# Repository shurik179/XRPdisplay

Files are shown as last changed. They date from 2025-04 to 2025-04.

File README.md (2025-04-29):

# XRP display
This project describes a small TFT display designed for use  with [XRP robot](https://experientialrobotics.org/)

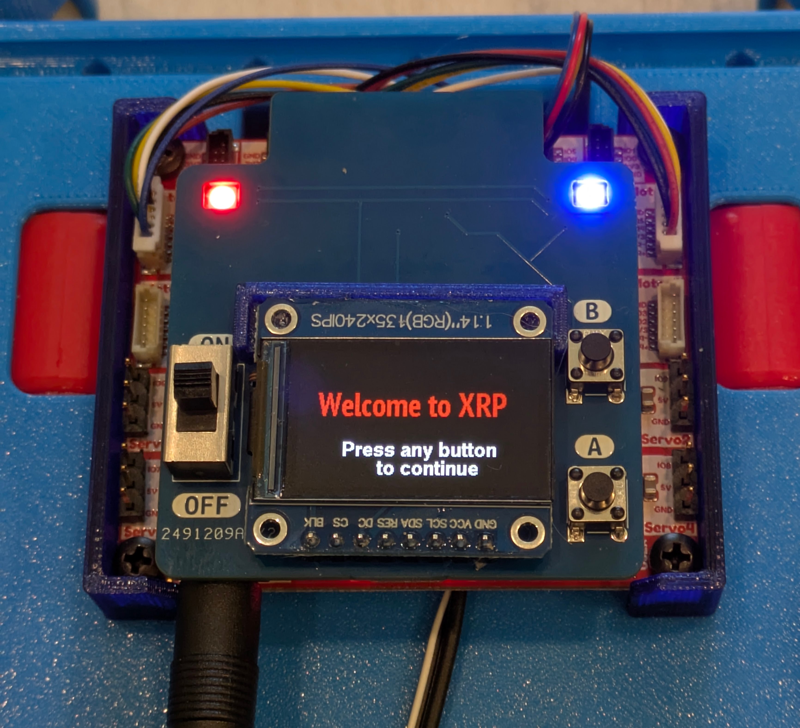
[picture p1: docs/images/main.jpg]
Main view


## Features

* 135x240 TFT SPI display
* two user buttons
* two addressable RGB LEDs (Neopixels)
* Power switch

## Documentation 
Detailed documentation is available at https://xrpdisplay.readthedocs.io/

## License
Everything in this repository is available under MIT license, except for the fonts in software/lib. See README file in that folder for license information.

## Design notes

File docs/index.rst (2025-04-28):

####################################
XRP display
####################################

Main view

This document describes the XRP display, an add-on board for `XRP robot <https://experientialrobotics.org/>`__

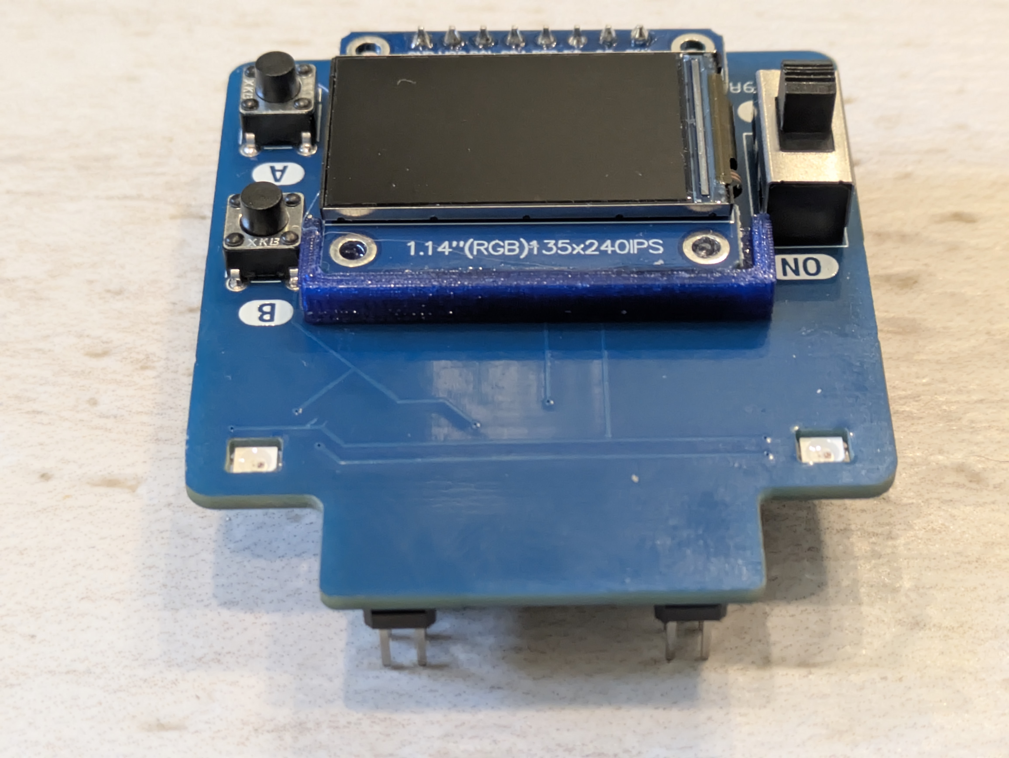
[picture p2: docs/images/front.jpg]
Front view


Below are the key features of this board.

* Plugs into the headers on XRP controller (warning: this doesn't work with Beta version!)
* provides a 135x240 color TFT display, using SPI bus of the XRP controller
* provides two addressable RGB LEDs (Neopixels)
* two user buttons 
* a power switch
* comes with an easy to use micropython library

All board design files and software are available from |github| under an open source license. 

.. toctree::
    :caption: Table of Contents
    :maxdepth: 1

    assembly
    usage

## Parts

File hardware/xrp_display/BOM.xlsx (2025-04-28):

Designator | Side | Description | Quantity | Link
D1, D2 | bottom | SK6812-MINI-E, reverse mount | 2 | C5149201 (https://www.lcsc.com/product-detail/RGB-LEDs-Built-in-IC_OPSCO-Optoelectronics-SK6812MINI-E_C5149201.html)
J1, J2 | bottom | PinHeader 2x20, SMD | 2 | C6332245 (https://www.lcsc.com/product-detail/Pin-Headers_Hanbo-Electronic-HB-PH9-254220PB2GOP_C6332245.html)
R1 | bottom | Resistor 0603, 33k | 1 | generic
SW1, SW2 | top | Tactile switch, 6x6mm | 2 | C381011 (https://www.lcsc.com/product-detail/Tactile-Switches_XKB-Connection-TC-1102-C-E-B_C381011.html)
SW3 | top | SPDT switch, SS12D | 1 | C319013 (https://www.lcsc.com/product-detail/Toggle-Switches_XKB-Connectivity-SS-12D10L3_C319013.html)
U1 | top | TFT_135x240_1_14in | 1 | AliExpress (https://www.aliexpress.us/item/3256801198423367.html)

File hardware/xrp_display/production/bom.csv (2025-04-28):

Designator | Footprint | Quantity | Value | LCSC Part #
D1, D2 | SK6812-MINI-E | 2 | SK6812MINI-E
J1, J2 | PinHeader_2x20_P2.54mm_Vertical_SMD | 2 | Conn_02x20_Odd_Even | C6332245
R1 | 0603 | 1 | 33k
SW1, SW2 | SW_TH_Tactile_Omron_B3F-10xx | 2 | SW_SPST
SW3 | SW_XKB_SS12D10L3 | 1 | SW_SPDT
U1 | TFT_135x240_1_14in | 1 | ST7789-TFT

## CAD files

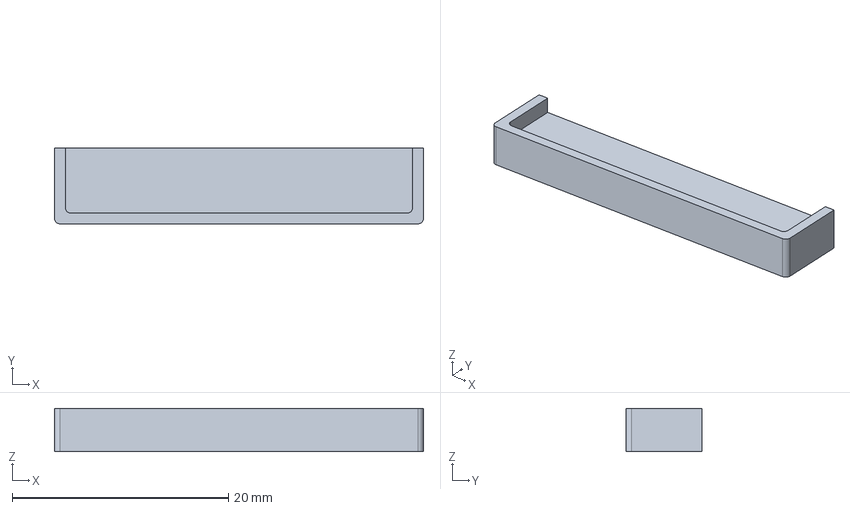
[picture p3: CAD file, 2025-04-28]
hardware/3dprinted/SPI display support v3.step
34.1 x 7.00 x 4.00 mm

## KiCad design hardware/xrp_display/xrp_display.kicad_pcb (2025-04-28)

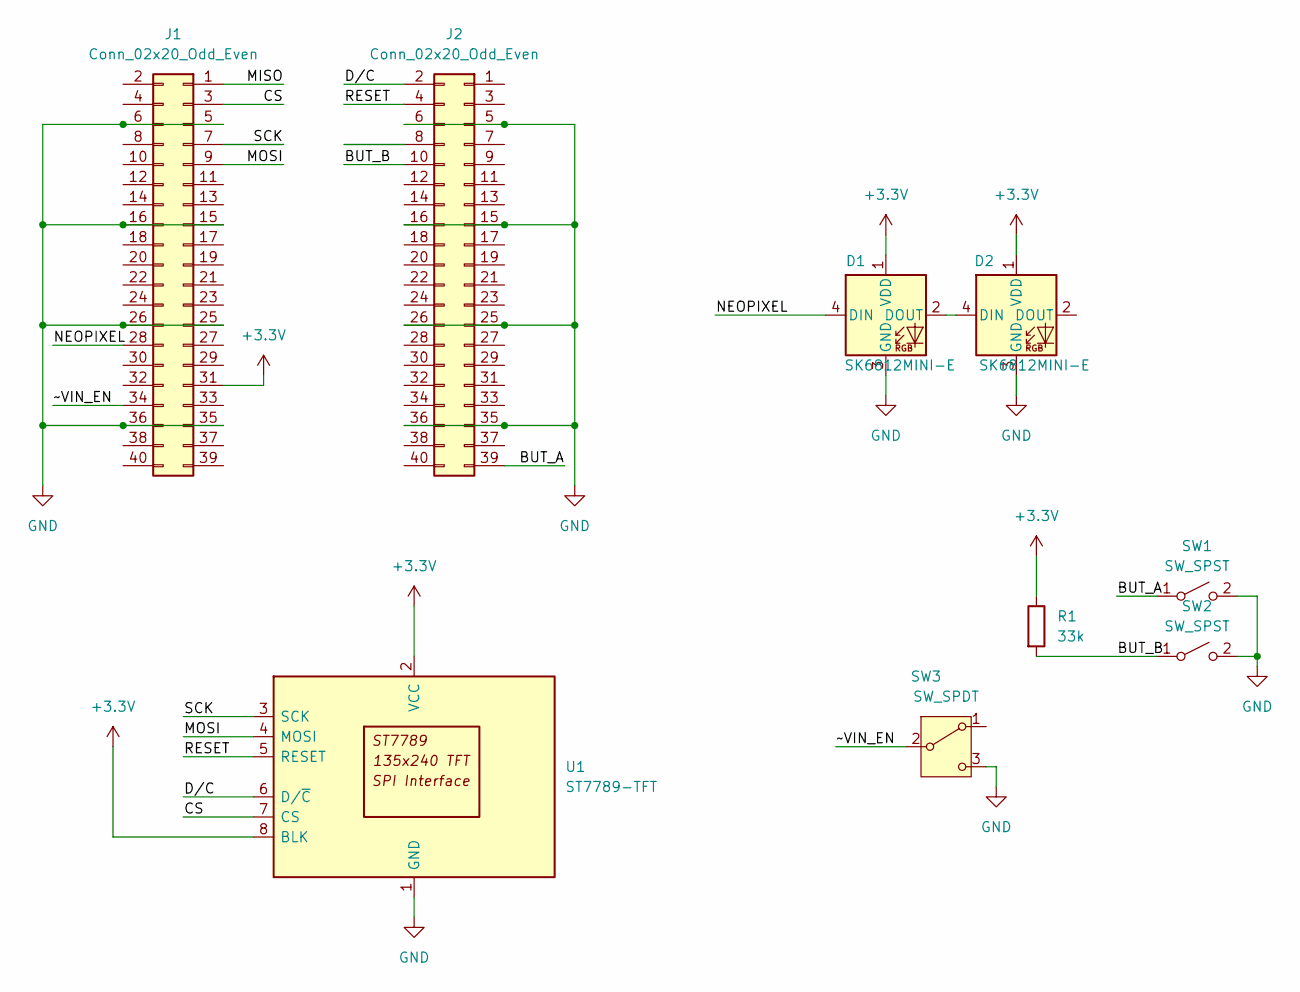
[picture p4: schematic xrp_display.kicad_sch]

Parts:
D1, D2: SK6812MINI-E; SK6812-MINI-E; LCSC C5149201
J1, J2: Conn_02x20_Odd_Even; PinHeader_2x20_P2.54mm_Vertical_SMD; LCSC C6332245
R1: 33k; R_0603_1608Metric
SW1, SW2: SW_SPST; SW_TH_Tactile_Omron_B3F-10xx
SW3: SW_SPDT; SW_XKB_SS12D10L3
U1: ST7789-TFT; TFT_135x240_1_14in

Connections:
+3.3V: D1.1 (VDD), D2.1 (VDD), J1.31, R1.1, U1.2 (VCC), U1.8 (BLK)
/BUT_A: J2.39, SW1.1 (A)
/BUT_B: J2.10, R1.2, SW2.1 (A)
/CS: J1.3, U1.7 (CS)
/D/C: J2.2, U1.6 (D/~C)
/MISO: J1.1
/MOSI: J1.9, U1.4 (MOSI)
/NEOPIXEL: D1.4 (DIN), J1.28
/RESET: J2.4, U1.5 (RESET)
/SCK: J1.7, U1.3 (SCK)
/~VIN_EN: J1.34, SW3.2 (B)
GND: D1.3 (GND), D2.3 (GND), J1.5, J1.6, J1.15, J1.16, J1.25, J1.26, J1.35, J1.36, J2.5, J2.6, J2.15, J2.16, J2.25, J2.26, J2.35, J2.36, SW1.2 (B), SW2.2 (B), SW3.3 (C), U1.1 (GND)
unnamed: D1.2 (DOUT), D2.4 (DIN)

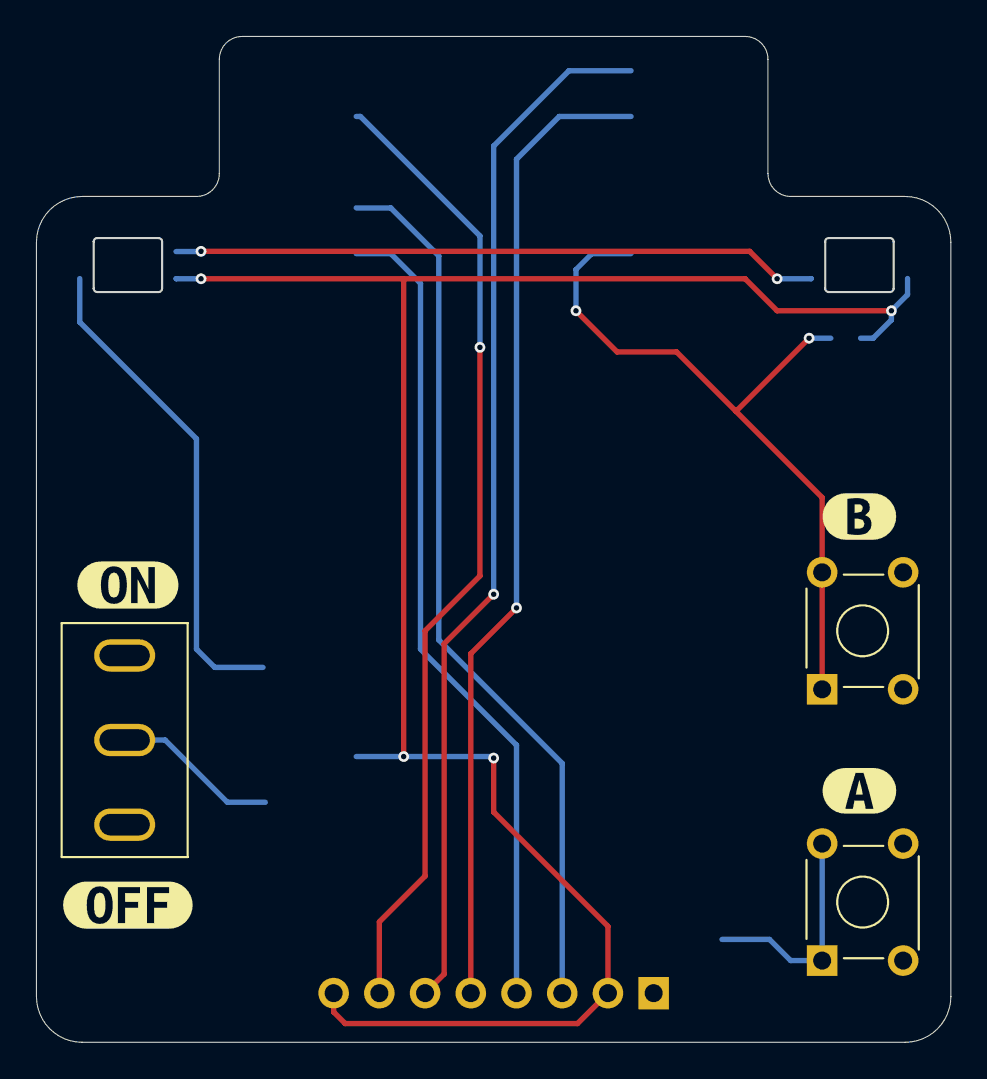
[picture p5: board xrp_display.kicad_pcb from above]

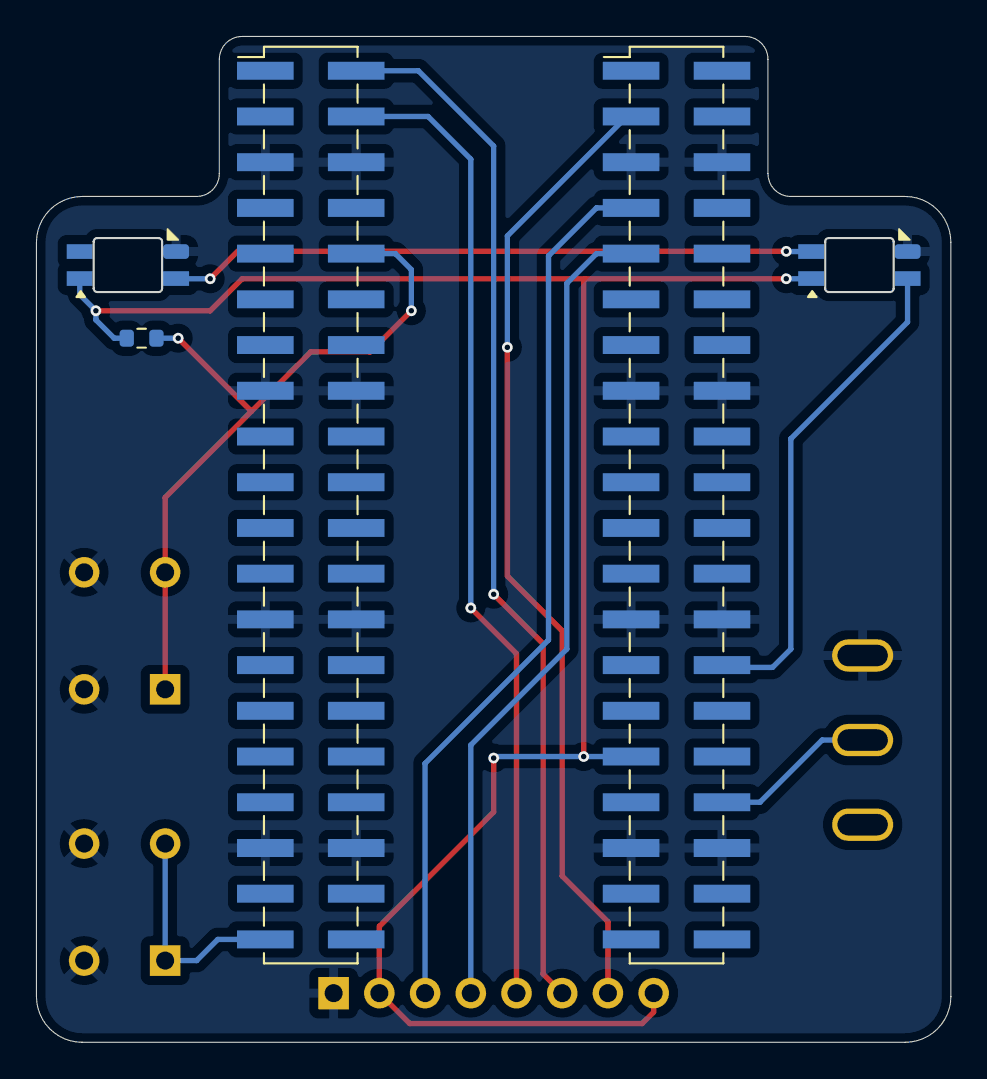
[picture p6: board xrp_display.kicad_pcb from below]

Board: 2 copper layers, 50.8 x 55.9 mm, 13 parts (5 on the bottom side), 12 nets.

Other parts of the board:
kibuzzard-67F032A5: G***; kibuzzard-67F032A5
kibuzzard-67F0329B: G***; kibuzzard-67F0329B
kibuzzard-67F03336: G***; kibuzzard-67F03336
kibuzzard-67F03342: G***; kibuzzard-67F03342

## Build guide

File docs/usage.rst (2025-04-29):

#################
Usage
#################

Attaching to XRP controller
############################
To attach the bord  to XRP controller, put the switch on the controller in "off" position. 
Connect all motors, servos, and sensors you intend to use to XRP controller. It is also advisabe to unplug 
the battery cable. 

Plug the board into the headers on the controller as shown in the photos. Make sure they 
are aligned and not off by one. When plugging in, you might need to push hard - but never push 
on the display itself.  

After plugging in, you can reconnect the battery and turn the switch on the board to "on"; switch on the 
controller should stay in off position.

Software installation
######################

Software is based on `st7789 display driver <https://github.com/easytarget/st7789-framebuffer>`__ 
by `Owen Carter <https://github.com/easytarget>`__. 

To install the software, download all files in `software/lib` folder of the |github| and copy them 
to /lib folder of your XRP controller (I use Thonny edtor for that). 

Now run `displaytest.py` file for demonstration of the board capabilities. This file is amply commented, 
making it easy to modify. 

Library reference
#################

To use the display in your own micropython code, use the commands below 

Initialization
--------------

To initialize the display, put this in the beginning of your code:

.. code-block:: python

   import xrpdisplay
   d = xrpdisplay.XrpDisplay()

All functions below will be methods of object `d`. 

Neopixels
---------

.. function:: set_leds(lcolor, rcolor)

   Sets the colors of the two Neopixel LEDs. `lcolor` sets the color of left LED, and `rcolor`, 
   of the right one.  `rcolor` is optional; if omitted, both LEDs are set to the same color. 
   Each color should be a triple of numbers ranging 0-255, desribing intensity of red, green, and blue LEDs, e.g. 
   `d.set_leds( (64, 0, 0 ) )` to set both LEDs red. 

   Note: it is recommended that you only use values 0-64 for each color intensity; even that is quite bright. 
   Using intensity of 255 woudl make the LEDs blindingly bright. 

Buttons
-------

.. function:: wait_for_button()

   Waits until user presses and releases one of the buttons. Returns button index: 1 for button A, 2 for button B. 

.. function:: is_button_pressed(button)

   Returns true if the corresponding button is pressed and false otherwise. `button` must be one of `d.buttonA`, `d.buttonB`. 

Display: basic operations
--------------------------       

.. function:: clear()

   Clears display, filling it with black pixels. 

.. function:: write_line(i, text, font = None, fg = None)

   Writes text on i-th line of display (i ranges 1--6). The text can be split into several lines using `\\n` escape sequence. 
   For example, `write_line(2, 'press button \\n to continue')` will write `press button` on line 2 and `to continue` on line 3. 
   This function automatically cleares these lines before writing new text. 

   Arguments `font` and `fg` (foreground color) are optional; if omitted, it will use default font (`d.smallfont`, 
   which is Helvetica bold) and white color. Other possible fonts are `d.smallfont2` (PT Sans Narrow_24), similar in size to the default 
   font but slightly more narrow, and `d.largefont` (PT Sans Narrow_32), a larger font. Note that `d.largefont` is taller than line 
   height, so using e.g. `d.write_line(2, "some text", font = d.largefont)` will actually get into the space reserved for line 3 as well as 2. 
   You might need to manually clear line 3 (by using `d.write_line(3,'')`) if it was non-empty. 

   Argument `fg` should be a color in RGB565 encoding; note that this is different 
   from the triple of values used for Neopixel colors -- these are not interchangeable. The library contains several predefined colors: 
   BLACK, DARKGREY, NAVY, BLUE, GREEN, TEAL, AZURE, LIME, CYAN, MAROON, PURPLE, OLIVE, GREY, SILVER, RED, ROSE, MAGENTA, ORANGE,
   YELLOW, WHITE
   (all are properties of xrpdisplay object, e.g. `d.BLACK`).

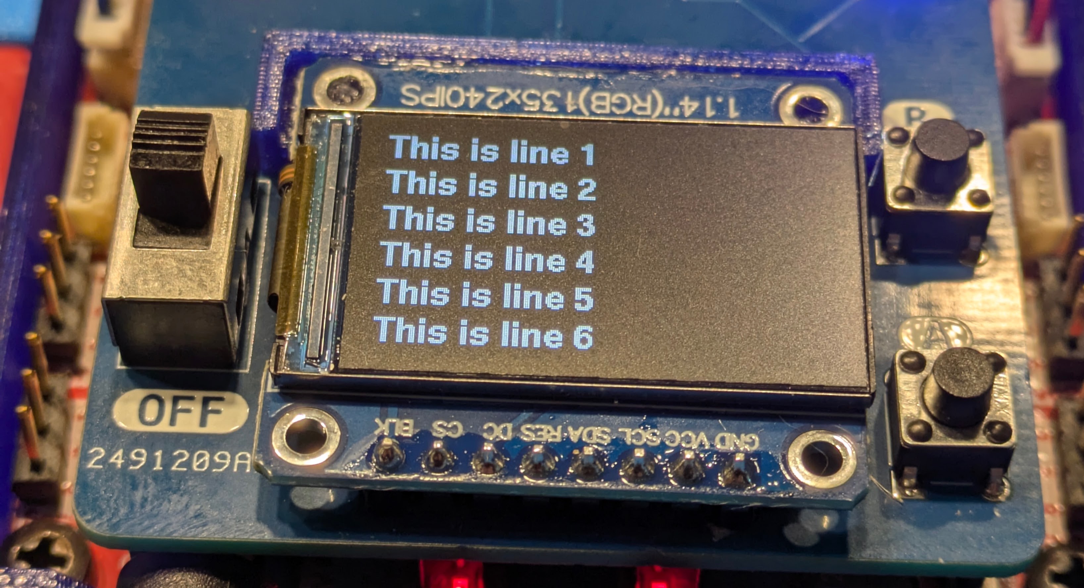
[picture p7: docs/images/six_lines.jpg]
Main view


Display: advanced 
------------------

When the above functions are not enough, you can use all graphics methods of micropython `framebuffer` class with `d.display` object, for example 
`d.display.rect(0,0,40,40, d.RED)`. Full list of supported framebuffer methods can be found at https://docs.micropython.org/en/latest/library/framebuf.html. 
Note that you will need to call `d.display.show()` to make the display show graphics constructed in this way (unlike `write_line` command that doesn't 
require that).

You can also place text in any position on screen, using `write()` method with any of the fonts (`d.smallfont`, `d,smallfont2`, `d.largefont`), 
e.g. 

.. code-block:: python

   d.largefont.write(20, 30, "Welcome!", fg = d.YELLOW)
   d.display.show()

Full documentation of `write()` method can be found at 
https://github.com/easytarget/microPyEZfonts/blob/main/WRITER.md .
As before, you will need to call `d.display.show()` to make these texts appear on screen.

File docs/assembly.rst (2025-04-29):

#######################
Board assembly
#######################
All board design files and BOM are in |github| under an open source license. Assemblying the board is 
straightforward - all you need is a decent sodlering iron - but time-consuming (you need to solder 80 pins). 

The Neopixel LEDs are soldered from the bottom of the board; pay attention to orientation 
(one of LED contacts has a corner cut off):

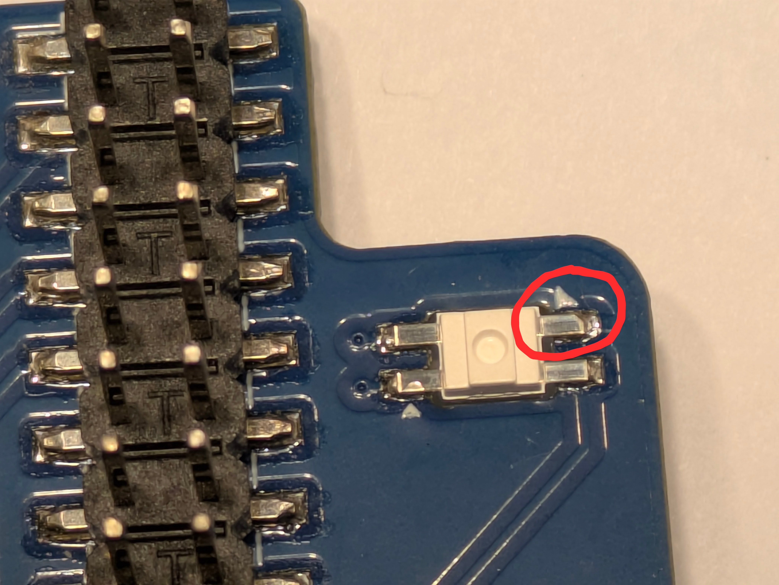
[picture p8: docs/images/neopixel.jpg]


Before soldering the TFT display, 3d print the support (in harware/3d printed folder in github) 
and glue it to the  display (I used contact adhesive for plastics). Be careful with the display, 
they are fragile.

Main view

After soldering all components, use flush cutters to trim the pins of the TFT display and the switch protruding 
from the bottom of the board.  

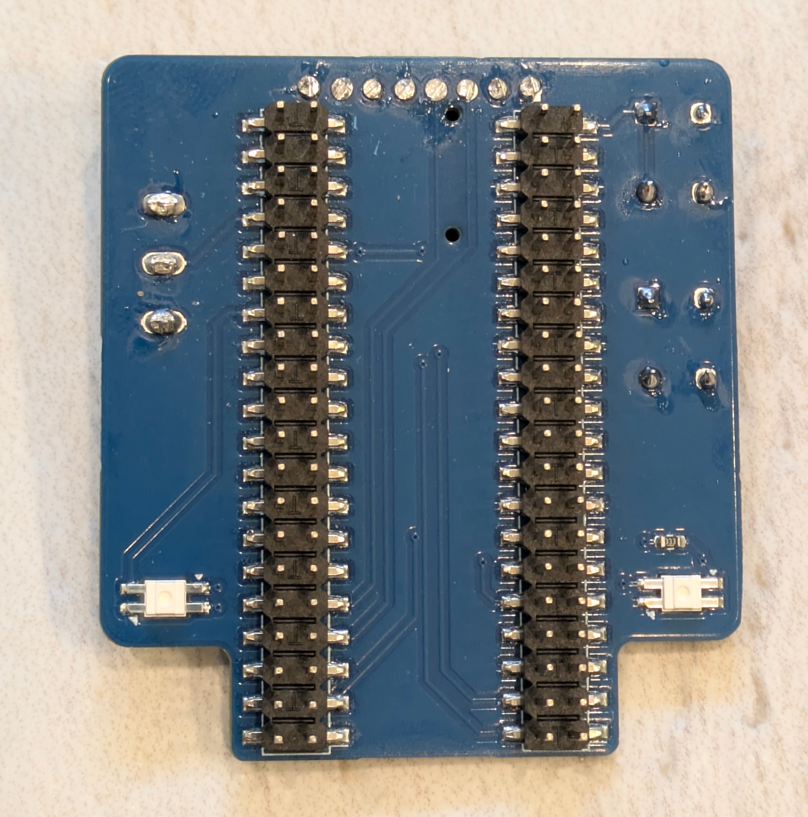
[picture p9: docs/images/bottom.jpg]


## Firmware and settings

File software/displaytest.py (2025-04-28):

from machine import Pin
import time
import xrpdisplay

# LED colors. These can't be used for display colors - those use different format!!
# As usual, each color ranges 0-255, but we suggest using values of 64 or lower - 
# even that is quite bright.
# Blue is dimmer than red and green, so we use higher values 
RED = (32,0,0)
GREEN = (0,32,0)
BLUE = (0,0,64)


d = xrpdisplay.XrpDisplay()
# Setting LED colors. First argument is color of left LED, second, of right.
# Second argument is optional; if omitted, same color is used for both LEDs:
# d.set_leds(RED)
d.set_leds(RED, BLUE)
d.write_line(5,'        Press any button \n               to continue')
# buttons. There are 2 buttons, labeled A and B. This command waits
# until a button is pressed, returns button index: 1 for A, 2 for B
x = d.wait_for_button()
# you can also check if a button is currently pressed:
# if d.is_button_pressed(d.buttonA): 
# basic display usage
d.clear()
d.write_line(2, f'Pressed button {x}')
# you can also choose font and text color (fg).
# Available fonts are d.smallfont (default), d.smallfont2 (slightly more narrow) and d.largefont
# Available colors (all prefixed with d.):
# BLACK, DARKGREY, NAVY,BLUE,GREEN,TEAL,AZURE,LIME,CYAN,MAROON
# PURPLE, OLIVE, GREY, SILVER, RED, ROSE, MAGENTA,ORANGE,YELLOW,WHITE

d.write_line(3, "smallfont2", font = d.smallfont2, fg = d.BLUE)
d.write_line(4, "Largefont", font = d.largefont)
# Note that largefont is higher than line height, so it also uses part of line 5
d.write_line(6, "Press button to continue", fg=d.YELLOW)
d.wait_for_button()
for i in range(1,7):
    d.write_line(i, f'This is line {i}')
time.sleep(3)
# more advanced use. You can use any framebuffer commands,
# see https://docs.micropython.org/en/latest/library/framebuf.html
# Note that you have to clear display before
# and use display.show() after graphics commands
# you can also use write command, documented at
# https://github.com/easytarget/microPyEZfonts/blob/main/WRITER.md
# with any of the avialable fonts (d.smallfont, d.smallfont2, d.largefont)
d.clear()
d.display.fill_rect(30,30, 180, 75, d.GREEN) 
d.largefont.write('THE END',60 , 52, fg = d.RED, bg = d.GREEN)
d.display.show()

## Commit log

2025-04-28 initial upload
    [BOM.xlsx, bom.csv, positions.csv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]
2025-04-28 added 3d printed support
    [SPI display support v3.step]
2025-04-30 Added battery voltage
